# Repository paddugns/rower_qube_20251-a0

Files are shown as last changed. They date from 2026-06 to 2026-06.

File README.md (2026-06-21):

# Rower Qube 20251-A0

RQ

The ROWER QUBE 20251 is a custom RP2040-based development board designed for 
embedded system development, rapid prototyping, and educational applications. The board 
integrates the Raspberry Pi RP2040 microcontroller with essential support circuitry including 
external QSPI flash memory, USB connectivity, clock generation circuitry, power 
management, and GPIO expansion headers. 
The RP2040 microcontroller features a dual-core ARM Cortex-M0+ processor operating at 
frequencies up to 133 MHz. Combined with 16 MB of external flash memory, the board 
provides a reliable platform for firmware development, sensor interfacing, communication 
systems, and real-time control applications. 
The compact layout and straightforward programming method make the ROWER QUBE 
20251 suitable for students, hobbyists, researchers, and embedded system developers 
seeking a versatile RP2040 development platform. 

## Schematic Diagram
The schematic diagram of the ROWER QUBE 20251 development board illustrates 
the complete hardware implementation of the RP2040-based system. The design 
integrates the RP2040 microcontroller with supporting circuits including power 
management, external flash memory, clock generation, USB communication, 
BOOTSEL functionality, and GPIO expansion headers. 

The power section provides regulated 3.3 V operation from either a USB connection 
or an external power source. The flash memory subsystem provides non-volatile 
storage for firmware and application data, while the crystal oscillator ensures 
accurate clock generation for reliable system operation. GPIO header connectors 
expose the microcontroller pins for interfacing with external peripherals and 
expansion modules.

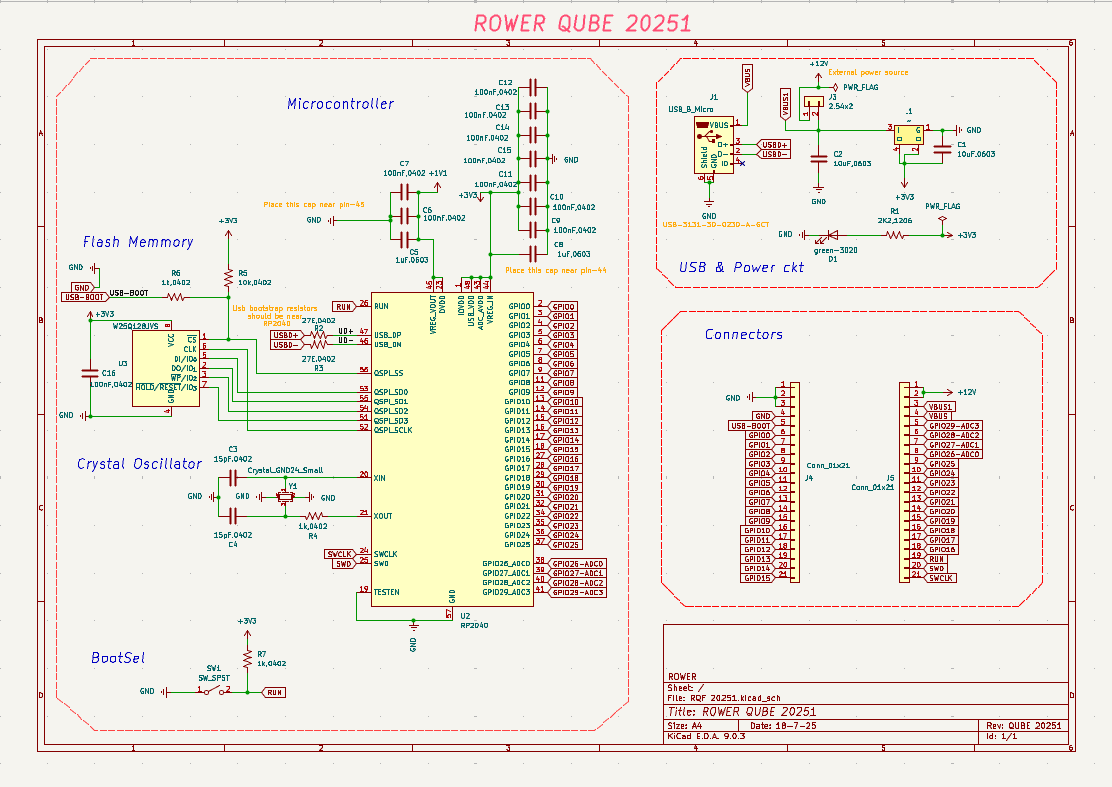
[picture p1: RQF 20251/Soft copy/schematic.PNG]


## 3D-View & PCB Layout
The three-dimensional representation of the ROWER QUBE 20251 development 
board provides a realistic view of component placement, connector orientation, and 
overall mechanical structure. The 3D model is generated directly from the PCB 
design data and serves as a valuable tool for validating component clearances, 
enclosure compatibility, and assembly requirements before fabrication.

The PCB layout of the ROWER QUBE 20251 development board was designed to 
provide reliable electrical performance, compact dimensions, and convenient access 
to all major interfaces. Special attention was given to component placement, power 
distribution, and signal routing to ensure stable operation of the RP2040 
microcontroller and associated circuitry. 
The board incorporates dedicated power and ground routing to minimize voltage 
drops and reduce electrical noise. Critical components such as the crystal oscillator, 
flash memory, and decoupling capacitors are placed close to the RP2040 
microcontroller to improve signal integrity and overall system reliability. 

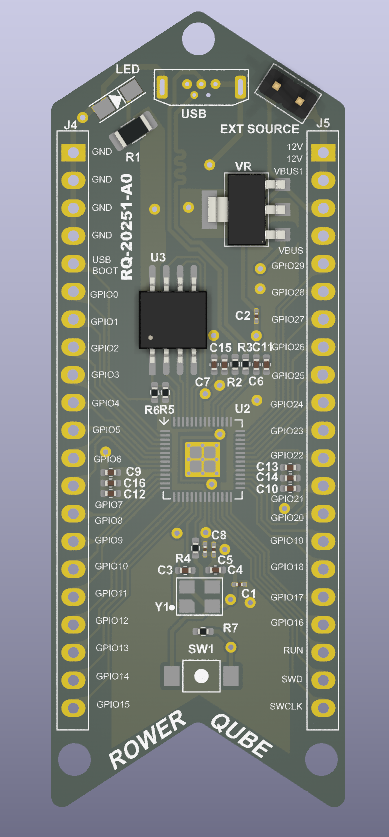
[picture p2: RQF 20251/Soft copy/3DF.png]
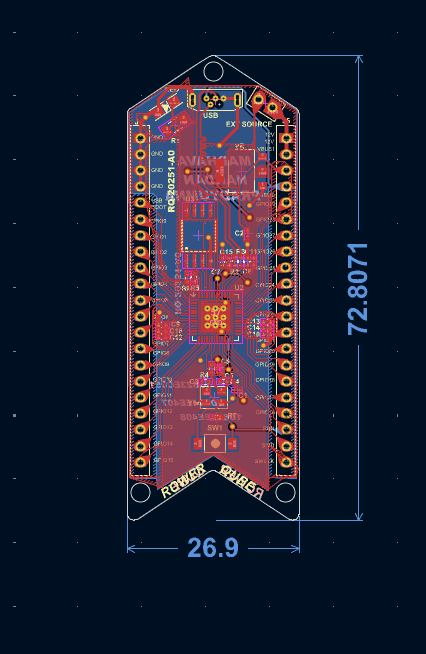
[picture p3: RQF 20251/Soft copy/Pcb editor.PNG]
 

## Gerber Images
Gerber file generation is a crucial step in the PCB manufacturing process, as it 
converts the completed PCB design into a standardized format that can be 
interpreted by fabrication machines. For the ROWER QUBE 20251 Development 
Board, Gerber files were generated using the KiCad PCB design software after 
completing the schematic design, PCB layout, and design rule verification. These files 
serve as the communication medium between the PCB designer and the 
manufacturing facility. 

The generated Gerber package includes all essential layers required for fabrication, 
such as the top and bottom copper layers, solder mask layers, silkscreen layers, 
paste layers, board outline, and drill files (Excellon format). Each layer contains 
precise information regarding track routing, pad locations, vias, component 
markings, and mechanical dimensions. This ensures that the fabricated board 
accurately matches the intended design specifications.

You can access the gerber images from the given zip file
[Gerber.zip](https://github.com/paddugns/rower_qube_20251-a0/blob/b17d841150b960b3ce6026f5780e1fa8d55f9cff/RQF%2020251/Soft%20copy/RQ-Datasheet.pdf)<br>

## Data Sheet
#### You can access the data sheet from the below link attached
[DataSheet.pdf](https://github.com/paddugns/rower_qube_20251-a0/blob/b17d841150b960b3ce6026f5780e1fa8d55f9cff/RQF%2020251/Soft%20copy/RQ-Datasheet.pdf)<br>

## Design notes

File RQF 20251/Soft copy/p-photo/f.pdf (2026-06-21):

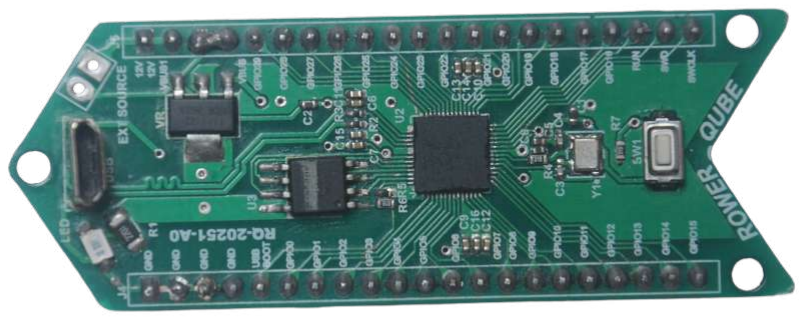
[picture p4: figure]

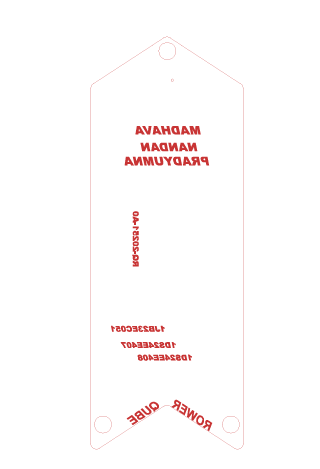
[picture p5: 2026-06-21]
RQF 20251/Soft copy/B Slikscreen.PNG

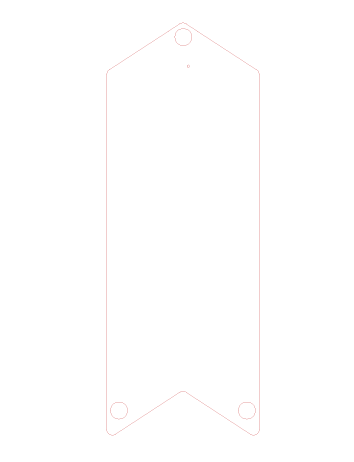
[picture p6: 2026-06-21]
RQF 20251/Soft copy/Edge cut.PNG

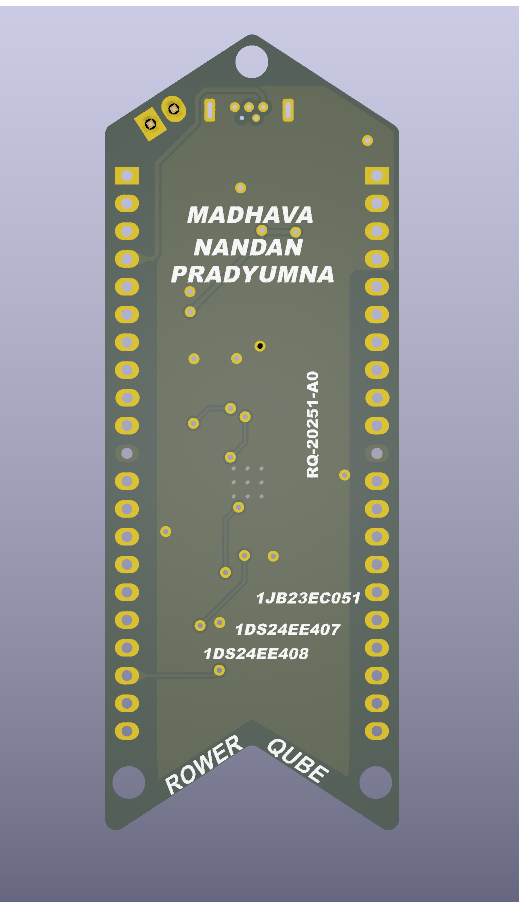
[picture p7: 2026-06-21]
RQF 20251/Soft copy/3DB.png

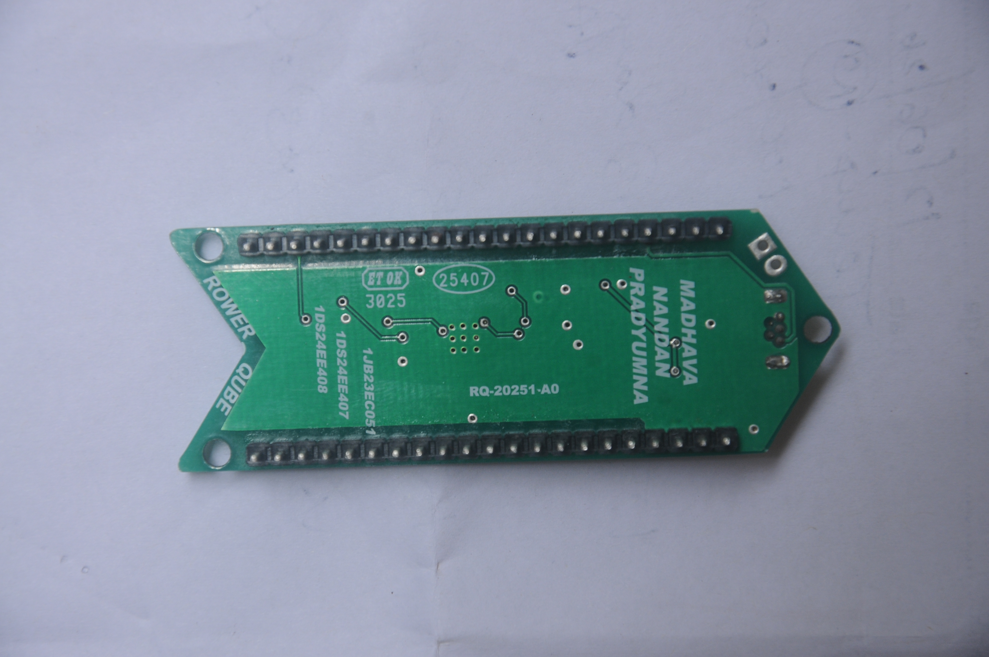
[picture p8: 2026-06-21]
RQF 20251/Soft copy/p-photo/b.JPG

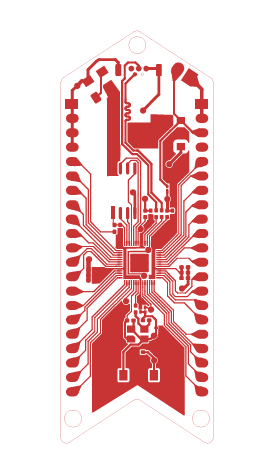
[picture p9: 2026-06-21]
RQF 20251/Soft copy/F Cu.PNG

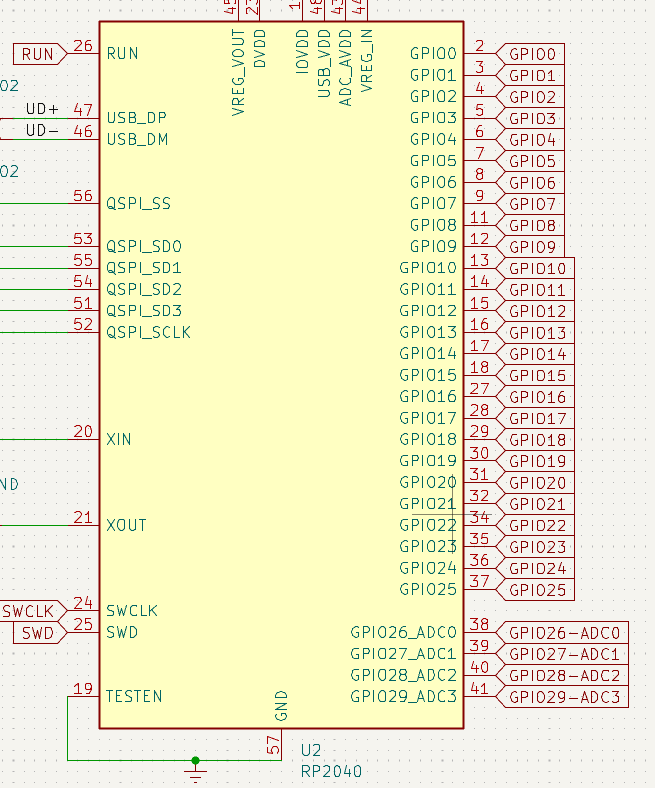
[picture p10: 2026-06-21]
RQF 20251/Soft copy/microcontroller.PNG

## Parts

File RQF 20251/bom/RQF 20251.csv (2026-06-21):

Reference | Qty | Value | Footprint | Description
.1 | 1 | ~ | Library:SOT-223-4
C1,C2 | 2 | 10uF,0603 | Capacitor_SMD:C_0201_0603Metric_Pad0.64x0.40mm_HandSolder | Unpolarized capacitor
C3,C4 | 2 | 15pF,0402 | Capacitor_SMD:C_0402_1005Metric_Pad0.74x0.62mm_HandSolder | Unpolarized capacitor
C5,C8 | 2 | 1uF,0603 | Capacitor_SMD:C_0201_0603Metric_Pad0.64x0.40mm_HandSolder | Unpolarized capacitor
C6,C7,C9,C10,C11,C12,C13,C14,C15,C16 | 10 | 100nF,0402 | Capacitor_SMD:C_0402_1005Metric_Pad0.74x0.62mm_HandSolder | Unpolarized capacitor
D1 | 1 | green-3020 | Library:LED-3020 | Light emitting diode
J1 | 1 | USB_B_Micro | Library:USB3131-30-0230-A | USB Micro Type B connector
J3 | 1 | 2.54x2 | Library:CONN-2.54X2 | Generic connector, single row, 01x02, script generated (kicad-library-utils/schlib/autogen/connector/)
J4,J5 | 2 | Conn_01x21 | Library:CONN-2X21 | Generic connector, single row, 01x21, script generated (kicad-library-utils/schlib/autogen/connector/)
R1 | 1 | 2K2,1206 | Resistor_SMD:R_1206_3216Metric_Pad1.30x1.75mm_HandSolder | Resistor, US symbol
R2,R3 | 2 | 27E,0402 | Resistor_SMD:R_0402_1005Metric_Pad0.72x0.64mm_HandSolder | Resistor, US symbol
R4,R6,R7 | 3 | 1k,0402 | Resistor_SMD:R_0402_1005Metric_Pad0.72x0.64mm_HandSolder | Resistor, US symbol
R5 | 1 | 10k,0402 | Resistor_SMD:R_0402_1005Metric_Pad0.72x0.64mm_HandSolder | Resistor, US symbol
SW1 | 1 | SW_SPST | Library:TACT-SW-3X4X2 | Single Pole Single Throw (SPST) switch
U2 | 1 | RP2040 | Library:QFN-56 | A microcontroller by Raspberry Pi
U3 | 1 | W25Q128JVS | Library:SOIC-8-208mil | 128Mbit / 16MiB Serial Flash Memory, Standard/Dual/Quad SPI, 2.7-3.6V, SOIC-8
Y1 | 1 | Crystal_GND24_Small | Library:CRYSTAL-ABM8 | Four pin crystal, GND on pins 2 and 4, small symbol

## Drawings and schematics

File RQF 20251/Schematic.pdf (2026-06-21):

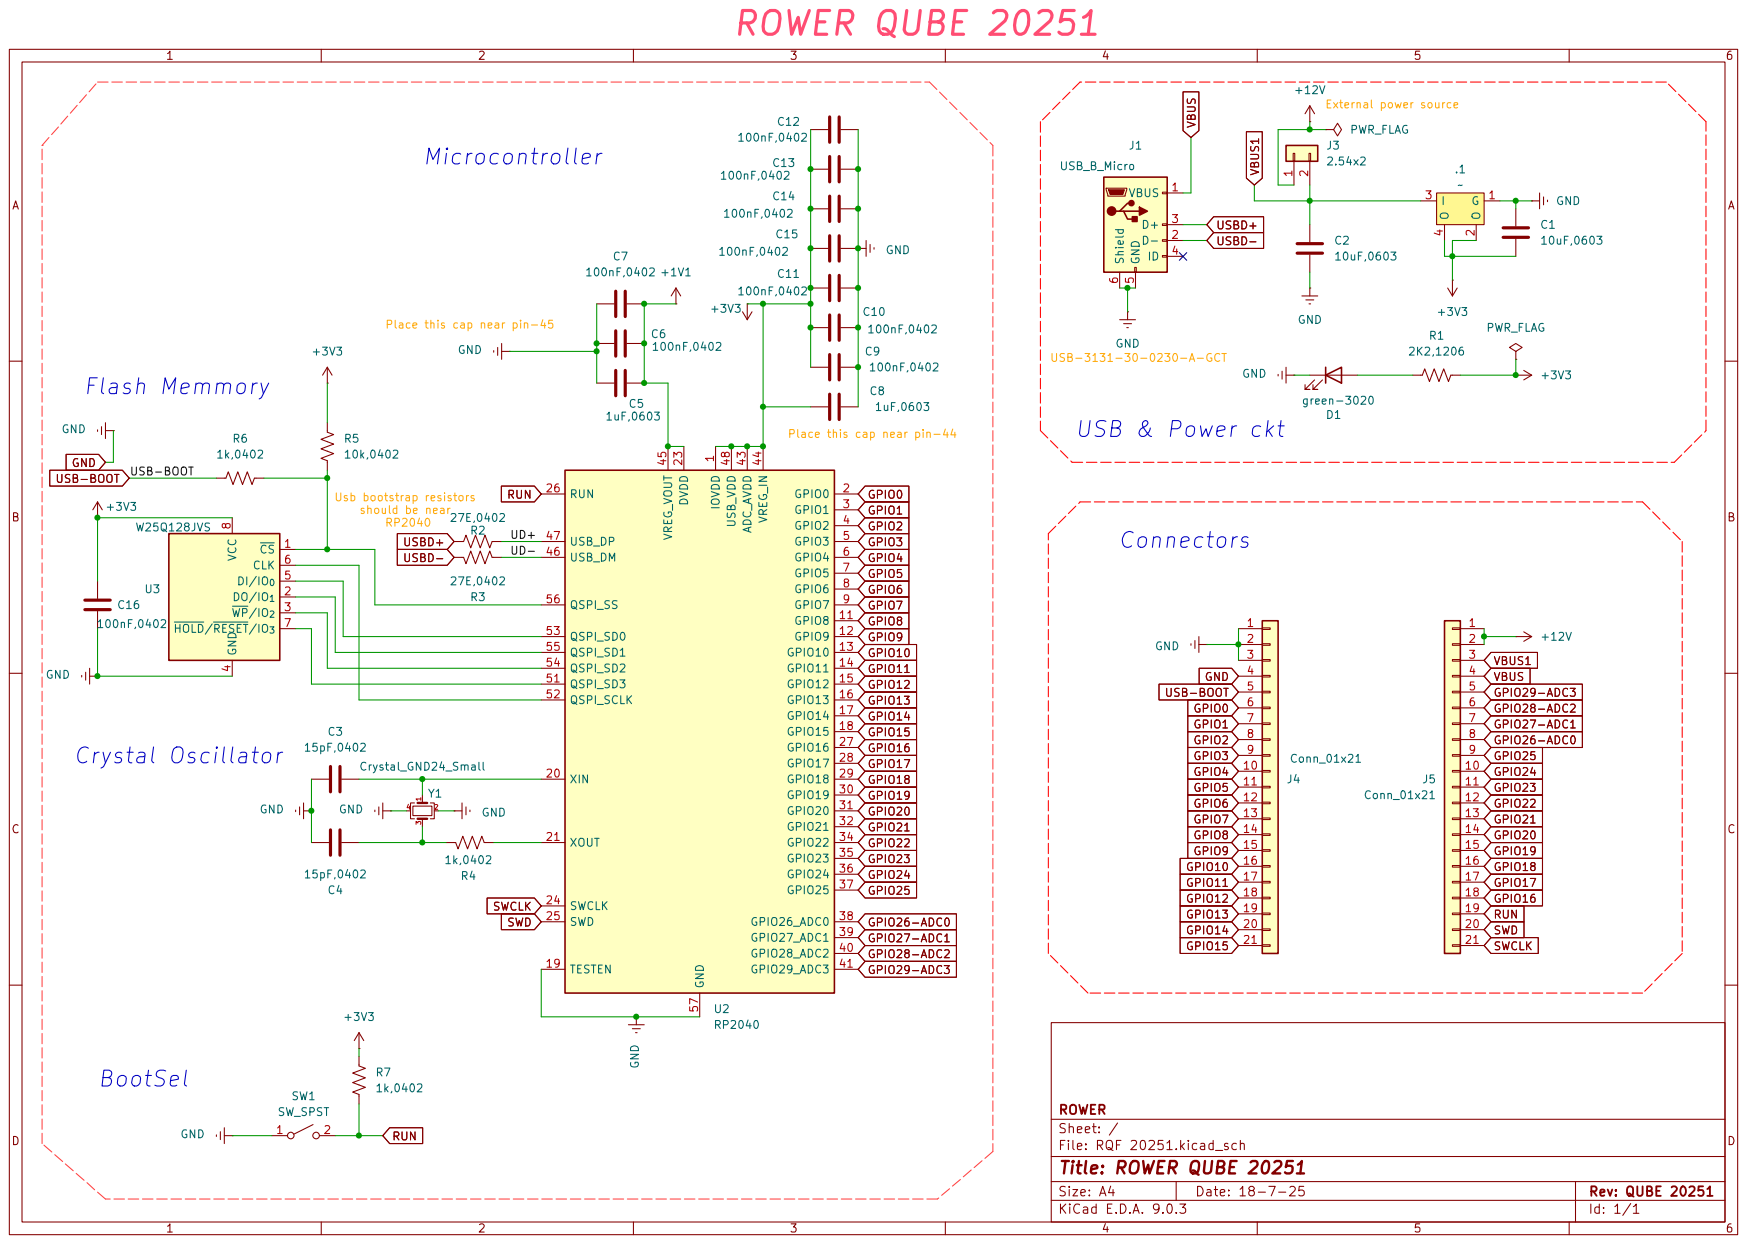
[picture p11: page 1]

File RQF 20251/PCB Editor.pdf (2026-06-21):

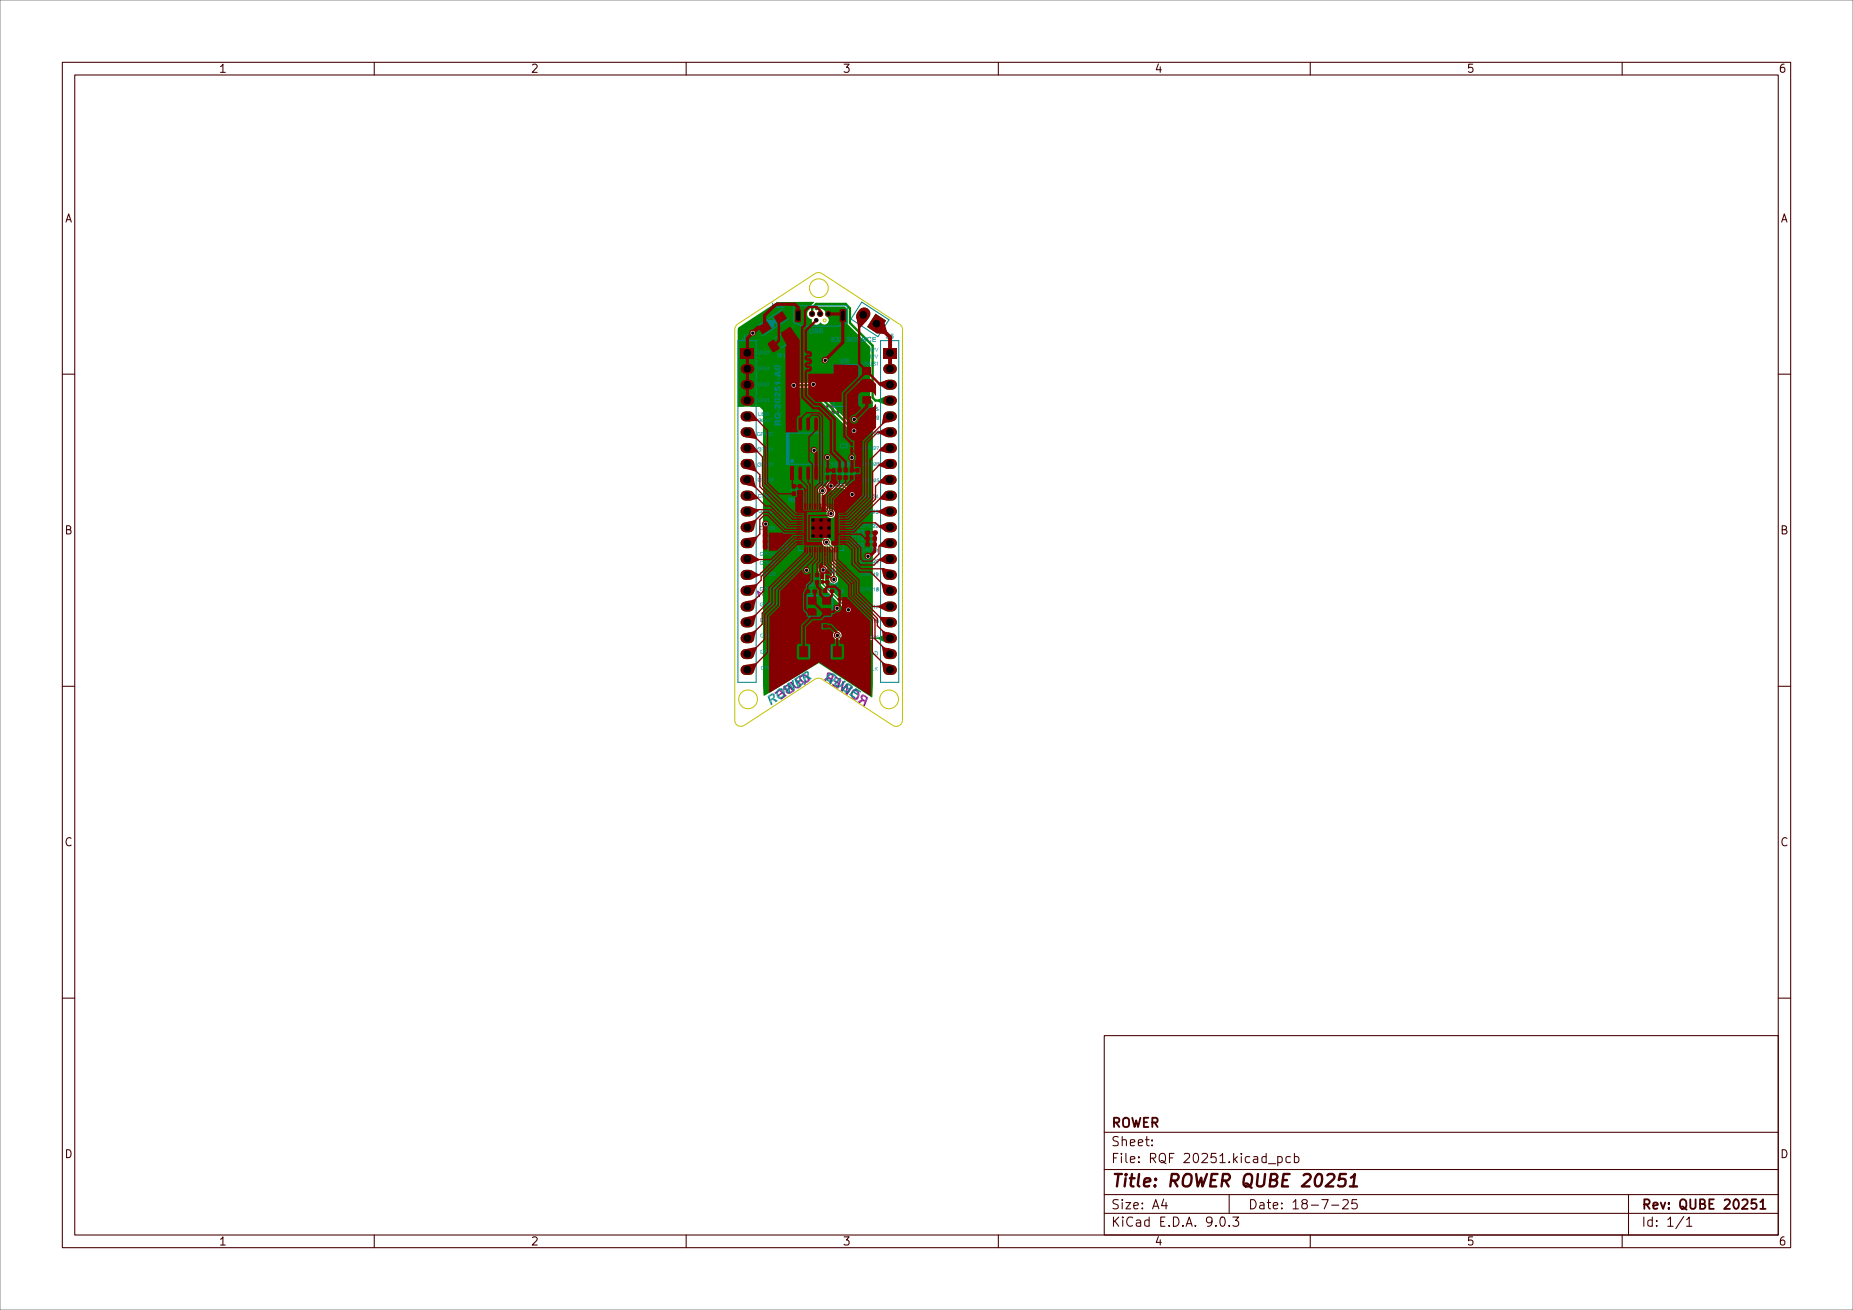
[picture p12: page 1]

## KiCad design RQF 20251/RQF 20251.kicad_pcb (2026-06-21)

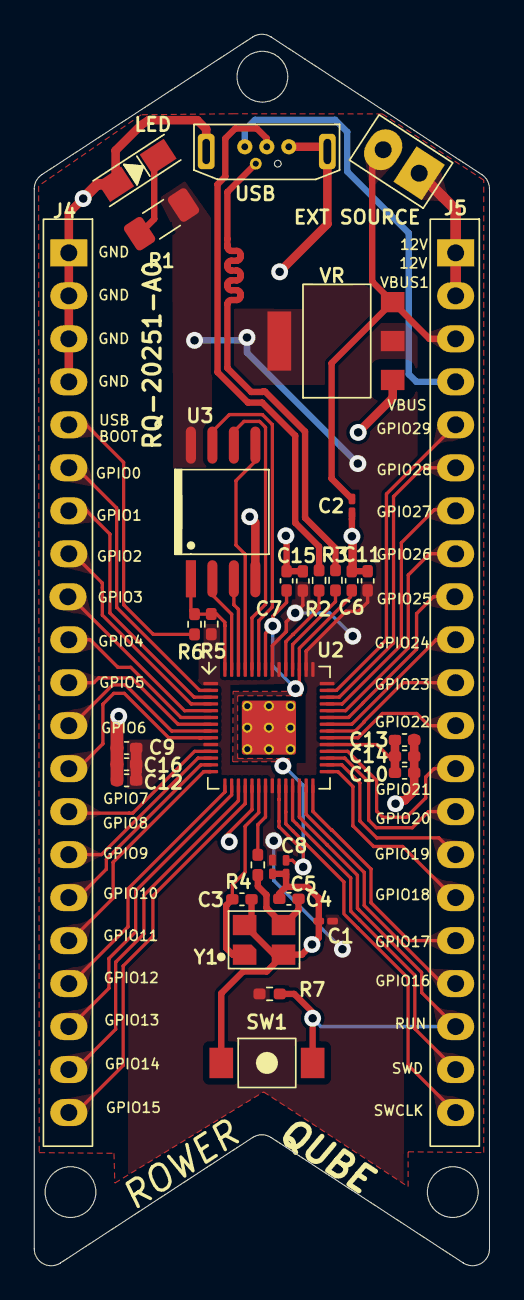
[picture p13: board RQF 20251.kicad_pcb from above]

Board: 2 copper layers, 26.9 x 72.8 mm, 33 parts (0 on the bottom side), 54 nets.

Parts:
C1, C2: 10uF,0603; C_0201_0603Metric_Pad0.64x0.40mm_HandSolder
C3, C4: 15pF,0402; C_0402_1005Metric_Pad0.74x0.62mm_HandSolder
C5, C8: 1uF,0603; C_0201_0603Metric_Pad0.64x0.40mm_HandSolder
C6, C7, C9, C10, C11, C12, C13, C14, C15, C16: 100nF,0402; C_0402_1005Metric_Pad0.74x0.62mm_HandSolder
EXT SOURCE: 2.54x2; CONN-2.54X2
J4, J5: Conn_01x21; CONN-2X21
LED: green-3020; LED-3020
R1: 2K2,1206; R_1206_3216Metric_Pad1.30x1.75mm_HandSolder
R2, R3: 27E,0402; R_0402_1005Metric_Pad0.72x0.64mm_HandSolder
R4, R6, R7: 1k,0402; R_0402_1005Metric_Pad0.72x0.64mm_HandSolder
R5: 10k,0402; R_0402_1005Metric_Pad0.72x0.64mm_HandSolder
SW1: SW_SPST; TACT-SW-3X4X2
U2: RP2040; QFN-56
U3: W25Q128JVS; SOIC-8-208mil
USB: USB_B_Micro; USB3131-30-0230-A
VR: SOT-223-4
Y1: Crystal_GND24_Small; CRYSTAL-ABM8

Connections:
+1V1: C5.2, C6.2, C7.2, U2.23 (DVDD), U2.45 (VREG_VOUT), U2.50 (DVDD)
+3V3: C1.2, C8.1, C9.1, C10.1, C11.1, C12.1, C13.1, C14.1, C15.1, C16.1, R1.2, R5.1, R7.1, U2.1 (IOVDD), U2.10 (IOVDD), U2.22 (IOVDD), U2.33 (IOVDD), U2.42 (IOVDD), U2.43 (ADC_AVDD), U2.44 (VREG_IN), U2.48 (USB_VDD), U2.49 (IOVDD), U3.8 (VCC), VR.2 (O), VR.4 (O)
+12V: EXT SOURCE.1, J5.1, J5.2
/UD+: R2.2, U2.47 (USB_DP)
/UD-: R3.2, U2.46 (USB_DM)
GND: C1.1, C2.2, C3.2, C4.1, C5.1, C6.1, C7.1, C8.2, C9.2, C10.2, C11.2, C12.2, C13.2, C14.2, C15.2, C16.2, J4.1, J4.2, J4.3, J4.4, LED.1 (K), SW1.1 (A), U2.19 (TESTEN), U2.57 (GND), U3.4 (GND), USB.5 (GND), USB.6 (Shield), USB.7, VR.1 (G), Y1.2, Y1.4
GPIO0: J4.6, U2.2 (GPIO0)
GPIO1: J4.7, U2.3 (GPIO1)
GPIO2: J4.8, U2.4 (GPIO2)
GPIO3: J4.9, U2.5 (GPIO3)
GPIO4: J4.10, U2.6 (GPIO4)
GPIO5: J4.11, U2.7 (GPIO5)
GPIO6: J4.12, U2.8 (GPIO6)
GPIO7: J4.13, U2.9 (GPIO7)
GPIO8: J4.14, U2.11 (GPIO8)
GPIO9: J4.15, U2.12 (GPIO9)
GPIO10: J4.16, U2.13 (GPIO10)
GPIO11: J4.17, U2.14 (GPIO11)
GPIO12: J4.18, U2.15 (GPIO12)
GPIO13: J4.19, U2.16 (GPIO13)
GPIO14: J4.20, U2.17 (GPIO14)
GPIO15: J4.21, U2.18 (GPIO15)
GPIO16: J5.18, U2.27 (GPIO16)
GPIO17: J5.17, U2.28 (GPIO17)
GPIO18: J5.16, U2.29 (GPIO18)
GPIO19: J5.15, U2.30 (GPIO19)
GPIO20: J5.14, U2.31 (GPIO20)
GPIO21: J5.13, U2.32 (GPIO21)
GPIO22: J5.12, U2.34 (GPIO22)
GPIO23: J5.11, U2.35 (GPIO23)
GPIO24: J5.10, U2.36 (GPIO24)
GPIO25: J5.9, U2.37 (GPIO25)
GPIO26-ADC0: J5.8, U2.38 (GPIO26_ADC0)
GPIO27-ADC1: J5.7, U2.39 (GPIO27_ADC1)
GPIO28-ADC2: J5.6, U2.40 (GPIO28_ADC2)
GPIO29-ADC3: J5.5, U2.41 (GPIO29_ADC3)
unnamed: C4.2, R4.1, Y1.3
unnamed: LED.2 (A), R1.1
unnamed: U2.52 (QSPI_SCLK), U3.6 (CLK)
unnamed: U2.53 (QSPI_SD0), U3.5 (DI/IO_{0})
unnamed: U2.55 (QSPI_SD1), U3.2 (DO/IO_{1})
unnamed: U2.54 (QSPI_SD2), U3.3 (~WP/IO_{2})
unnamed: U2.51 (QSPI_SD3), U3.7 (~HOLD/~RESET/IO_{3})
unnamed: R5.2, R6.2, U2.56 (QSPI_SS), U3.1 (~CS)
unnamed: C3.1, U2.20 (XIN), Y1.1
unnamed: R4.2, U2.21 (XOUT)
RUN: J5.19, R7.2, SW1.2 (B), U2.26 (RUN)
SWCLK: J5.21, U2.24 (SWCLK)
SWD: J5.20, U2.25 (SWD)
USB-BOOT: J4.5, R6.1
USBD+: R2.1, USB.3 (D+)
USBD-: R3.1, USB.2 (D-)
VBUS: J5.4, USB.1 (VBUS)
VBUS1: C2.1, EXT SOURCE.2, J5.3, VR.3 (I)
